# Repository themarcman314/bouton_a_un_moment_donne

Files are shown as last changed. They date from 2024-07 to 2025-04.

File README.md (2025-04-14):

## HW prototype
kicad schematic and board files as well as BOM and step files are available here.
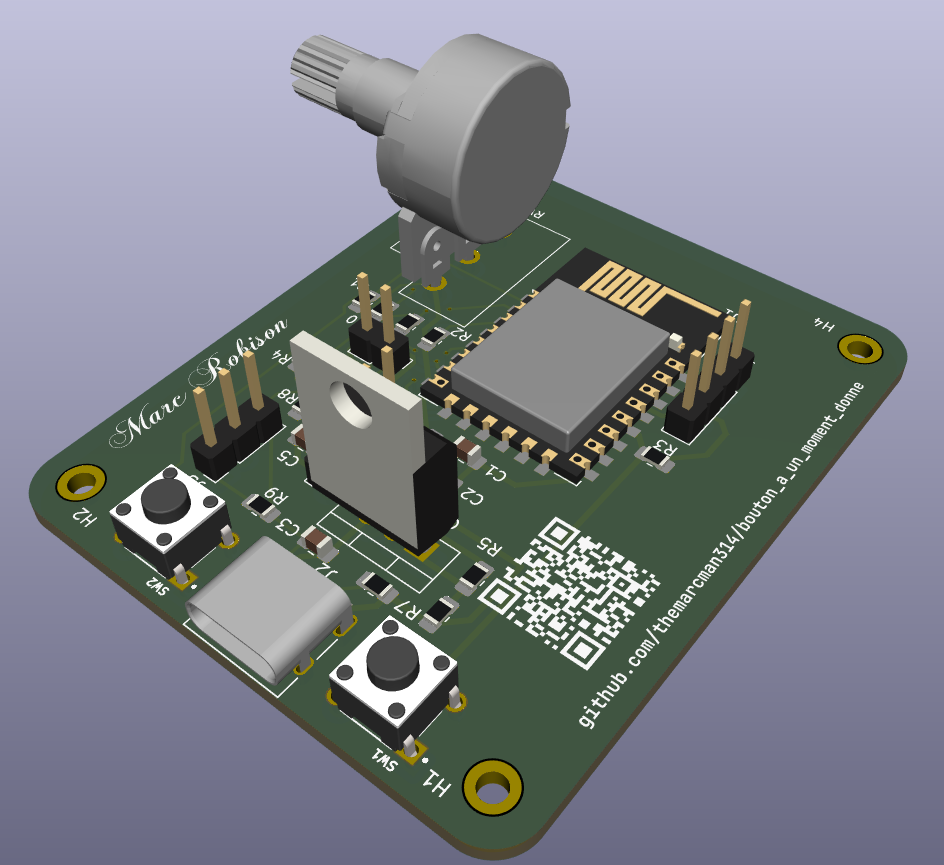
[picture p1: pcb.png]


This code is not even in alpha.

Was trying to figure out a version name so I asked chatgpt :

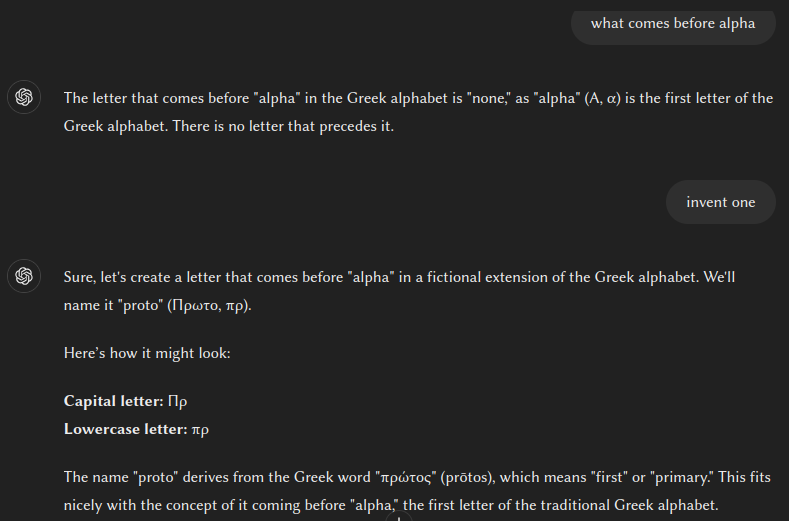
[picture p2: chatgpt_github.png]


This code is in "proto".

I know it might sound similar to some but dont confuse this with "production".

## Usage

### Clone the repo
HTTPS
```bash
$ git clone "https://github.com/themarcman314/bouton_a_un_moment_donne.git"
```
SSH
```bash
$ git clone git@github.com:themarcman314/bouton_a_un_moment_donne.git
```

### Wire I2S pins from ESP8266NodeMCU to MAX98357A DAC & class D amp
Kindly RTFM and follow wiring from here :
https://github.com/earlephilhower/ESP8266Audio?tab=readme-ov-file#i2s-dacs

### Flash firmware
Open `.ino` file with the arduino ide and click the arrow pointing right to flash.

### Configure audio files
1. Connect to the WAP with Wi-Fi enabled device.
SSID name is `fbi_van`

2. Portal with the configuration page should open automatically.
If not just go to `192.168.1.1` or any ip at all really.

3. Upload small mp3 files (2 MByte or smaller works well). My esp8266 module is limited to 4MB, I am allocating 3MB to the filesystem. Even when doing so, the amount of files that can be uploaded is limited depending on the bit rate, duration of audio, etc...
Remaining space is displayed on the main page.

Be patient when uploading a file.
Uploading a 1.1 MByte file took me 15 seconds which gives a transfering speed of about 1.1 * 8 / 15 = 0.58 MBit/s

Below is the configuration I set in arduino-ide to increase the upload speed

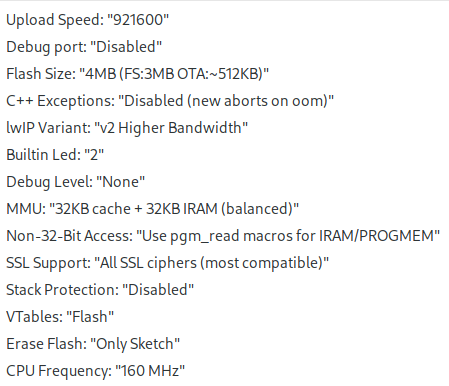
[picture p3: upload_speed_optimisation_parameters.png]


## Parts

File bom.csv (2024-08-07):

Id | Référence | Empreinte | Quantité | Désignation | Fournisseur et réf
1 | J3 | PinHeader_1x03_P2.54mm_Vertical | 1 | Conn_01x03_Pin
2 | J2 | PinHeader_1x04_P2.54mm_Vertical | 1 | Conn_01x04_Pin
3 | R1 | R_0805_2012Metric_Pad1.20x1.40mm_HandSolder | 1 | 1M
4 | C4 | C_0805_2012Metric_Pad1.18x1.45mm_HandSolder | 1 | 10uF
5 | RV1 | Potentiometer_Piher_T-16H_Single_Horizontal | 1 | R_Potentiometer
6 | A1 | SEEED_113990105 | 1 | 113990105
7 | R3 | R_0805_2012Metric_Pad1.20x1.40mm_HandSolder | 1 | 10K
8 | J1 | JST_SUR_SM02B-SURS-TF_1x02-1MP_P0.80mm_Horizontal | 1 | Conn_01x02
9 | U1 | TQFN-16-1EP_3x3mm_P0.5mm_EP1.23x1.23mm | 1 | MAX98357A
10 | R2 | R_0805_2012Metric_Pad1.20x1.40mm_HandSolder | 1 | R
11 | C3 | C_0805_2012Metric_Pad1.18x1.45mm_HandSolder | 1 | 0.1uF

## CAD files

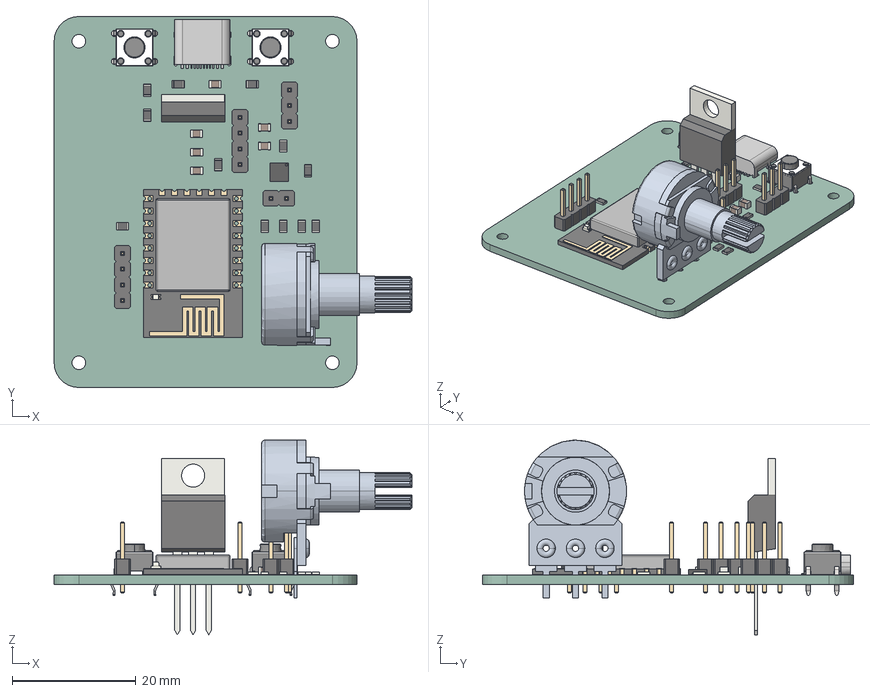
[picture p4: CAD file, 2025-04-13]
sound_box.step
57.9 x 60.0 x 31.5 mm
PinHeader_1x04_P2.54mm_Vertical x 2
QFN-16 (3x3) Part1
QFN-16 (3x3) Part2 x 16
tactileswitch-short x 2
R_0805_2012Metric x 12
TO-220-3_Vertical
ESP-12E
C_0805_2012Metric x 6
HRO TYPE-C-31-M-12
Potentiometer
PinHeader_1x02_P2.54mm_Vertical
PinHeader_1x03_P2.54mm_Vertical
sound_box_PCB

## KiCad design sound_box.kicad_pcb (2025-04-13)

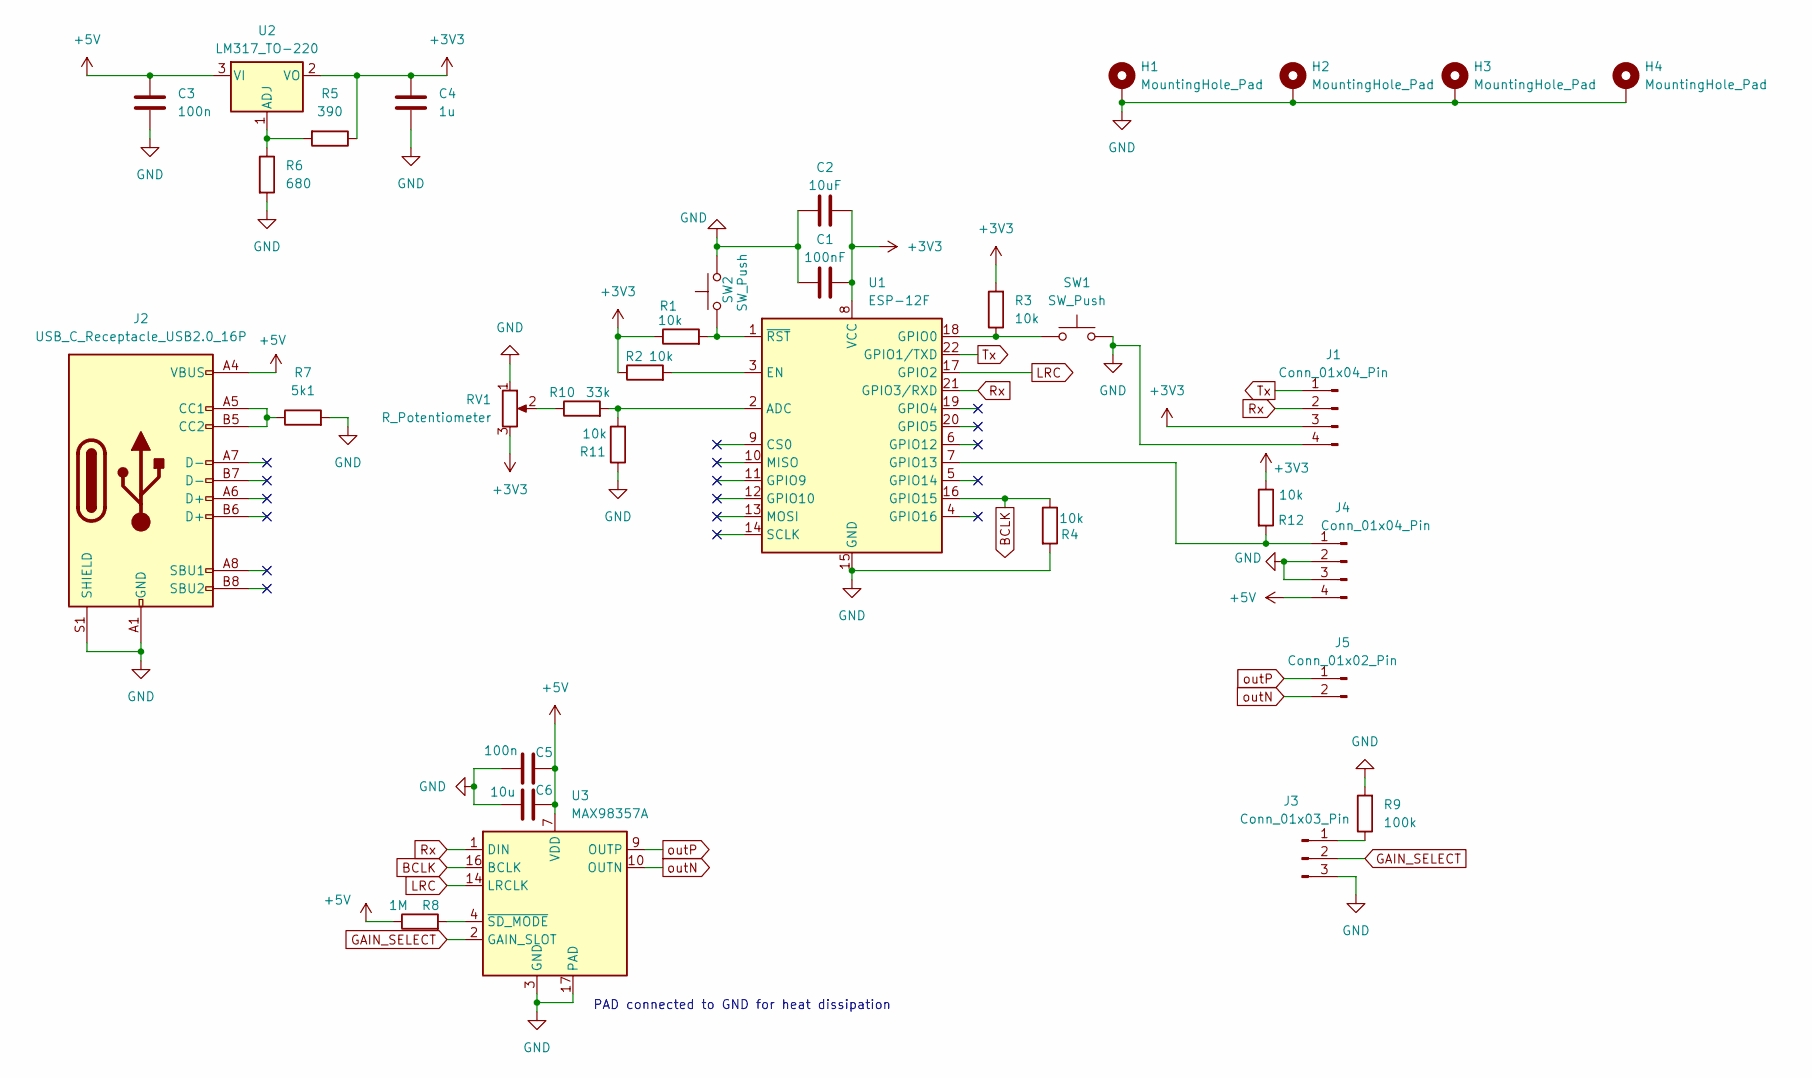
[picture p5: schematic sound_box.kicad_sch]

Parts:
C1: 100nF; C_0805_2012Metric_Pad1.18x1.45mm_HandSolder
C2: 10uF; C_0805_2012Metric_Pad1.18x1.45mm_HandSolder
C3, C5: 100n; C_0805_2012Metric_Pad1.18x1.45mm_HandSolder
C4: 1u; C_0805_2012Metric_Pad1.18x1.45mm_HandSolder
C6: 10u; C_0805_2012Metric_Pad1.18x1.45mm_HandSolder
H1, H2, H3, H4: MountingHole_Pad; MountingHole_2.2mm_M2_DIN965_Pad
J1, J4: Conn_01x04_Pin; PinHeader_1x04_P2.54mm_Vertical
J2: USB_C_Receptacle_USB2.0_16P; USB_C_Receptacle_HRO_TYPE-C-31-M-12
J3: Conn_01x03_Pin; PinHeader_1x03_P2.54mm_Vertical
J5: Conn_01x02_Pin; PinHeader_1x02_P2.54mm_Vertical
R1, R2, R3, R4, R11, R12: 10k; R_0805_2012Metric_Pad1.20x1.40mm_HandSolder
R5: 390; R_0805_2012Metric_Pad1.20x1.40mm_HandSolder
R6: 680; R_0805_2012Metric_Pad1.20x1.40mm_HandSolder
R7: 5k1; R_0805_2012Metric_Pad1.20x1.40mm_HandSolder
R8: 1M; R_0805_2012Metric_Pad1.20x1.40mm_HandSolder
R9: 100k; R_0805_2012Metric_Pad1.20x1.40mm_HandSolder
R10: 33k; R_0805_2012Metric_Pad1.20x1.40mm_HandSolder
RV1: R_Potentiometer; Potentiometer_Piher_T-16H_Single_Horizontal
SW1, SW2: SW_Push; SW_1825910-6-4
U1: ESP-12F; ESP-12E
U2: LM317_TO-220; TO-220-3_Vertical
U3: MAX98357A; TQFN-16-1EP_3x3mm_P0.5mm_EP1.23x1.23mm

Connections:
+3V3: C1.2, C2.2, C4.1, J1.3, R1.1, R2.1, R3.2, R5.1, R12.1, RV1.3, U1.8 (VCC), U2.2 (VO)
+5V: C3.1, C5.2, C6.2, J2.A4 (VBUS), J2.A9 (VBUS), J2.B4 (VBUS), J2.B9 (VBUS), J4.4, R8.1, U2.3 (VI), U3.7 (VDD), U3.8 (VDD)
BCLK: R4.1, U1.16 (GPIO15), U3.16 (BCLK)
GAIN_SELECT: J3.2, U3.2 (GAIN_SLOT)
GND: C1.1, C2.1, C3.2, C4.2, C5.1, C6.1, H1.1, H2.1, H3.1, H4.1, J1.4, J2.A1 (GND), J2.A12 (GND), J2.B1 (GND), J2.B12 (GND), J2.S1 (SHIELD), J3.3, J4.2, J4.3, R4.2, R6.2, R7.2, R9.2, R11.1, RV1.1, SW1.2, SW2.2, U1.15 (GND), U3.3 (GND), U3.11 (GND), U3.15 (GND), U3.17 (PAD)
LRC: U1.17 (GPIO2), U3.14 (LRCLK)
unnamed: J2.A5 (CC1), J2.B5 (CC2), R7.1
unnamed: J3.1, R9.1
unnamed: J4.1, R12.2, U1.7 (GPIO13)
unnamed: R10.1, RV1.2
unnamed: R10.2, R11.2, U1.2 (ADC)
unnamed: R2.2, U1.3 (EN)
unnamed: R3.1, SW1.1, U1.18 (GPIO0)
unnamed: R1.2, SW2.1, U1.1 (~RST)
unnamed: R5.2, R6.1, U2.1 (ADJ)
unnamed: R8.2, U3.4 (~SD_MODE)
Rx: J1.2, U1.21 (GPIO3/RXD), U3.1 (DIN)
Tx: J1.1, U1.22 (GPIO1/TXD)
outN: J5.2, U3.10 (OUTN)
outP: J5.1, U3.9 (OUTP)

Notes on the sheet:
PAD connected to GND for heat dissipation

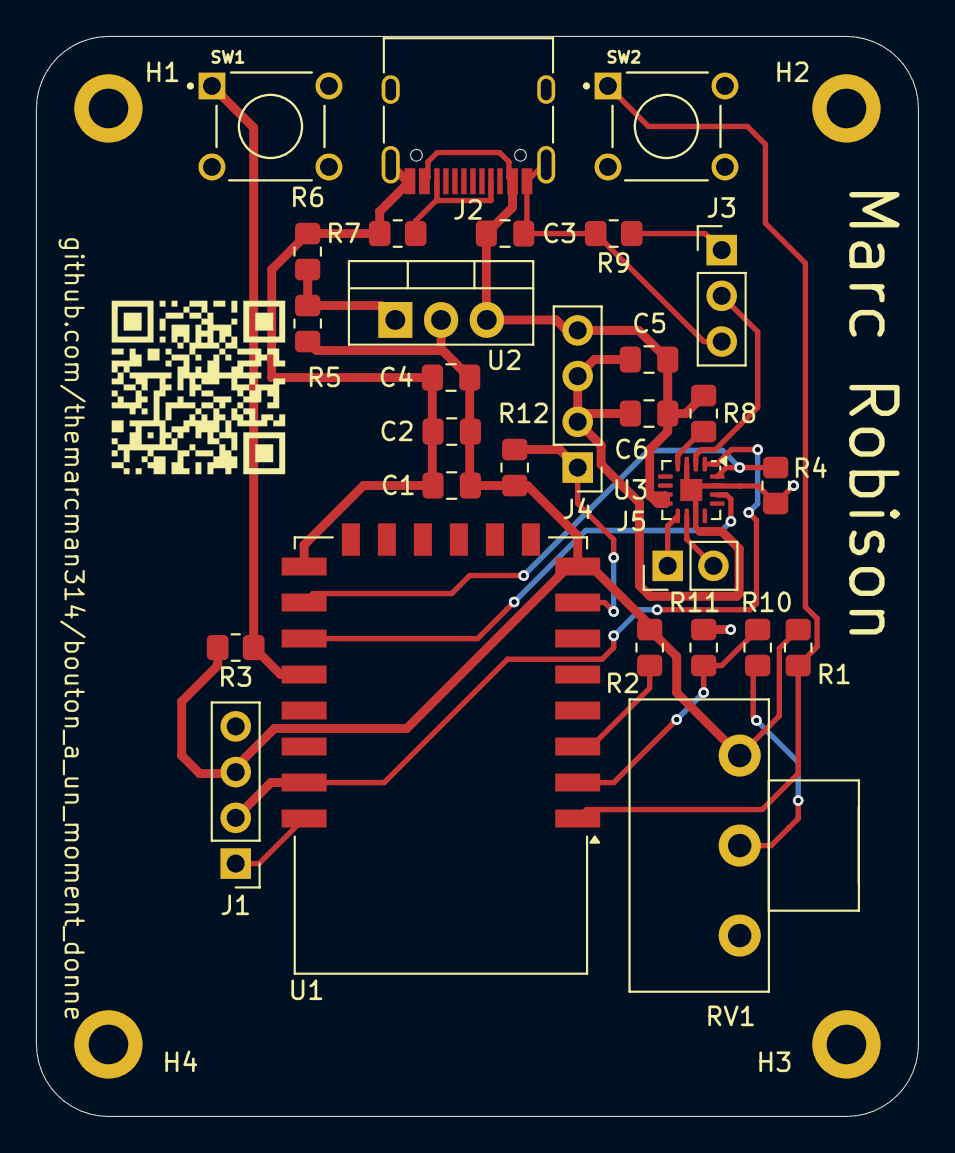
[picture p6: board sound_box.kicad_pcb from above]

Board: 2 copper layers, 49.0 x 60.0 mm, 33 parts (0 on the bottom side), 20 nets.

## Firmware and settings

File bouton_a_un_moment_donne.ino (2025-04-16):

// #include "LittleFS.h"
// #define HTTP_UPLOAD_BUFLEN 4096


#include <Arduino.h>
#include "AudioFileSourceSPIFFS.h"
#include "AudioGeneratorMP3.h"
#include "AudioOutputI2SNoDAC.h"


#include <ESP8266WiFi.h>
#include <WiFiClient.h>
#include <ESP8266WebServer.h>
#include <DNSServer.h>
#include "pages.h"
#include "style.h"

#include "ESP8266TimerInterrupt.h"

// set max space for flash
// FLASH_MAP_SETUP_CONFIG(FLASH_MAP_MAX_FS)
#ifndef APSSID
#define APSSID "fbi_van"
#define APPSK "password"
#endif

#define TIMER_INTERVAL_MS        1000

void Playsong(void);


static const char TEXT_PLAIN[] PROGMEM = "text/plain";
File uploadFile;

AudioGeneratorMP3 *mp3;
AudioFileSourceSPIFFS *file;
AudioOutputI2S *out;


String selected_file;

const byte DNS_PORT = 53;
DNSServer dnsServer;

/* Set these to your desired credentials. */
const char *ssid = APSSID;
const char *password = APPSK;

ESP8266WebServer server(80);

ESP8266Timer ITimer;

volatile bool updateVolume = false;
volatile bool stop = false;


void IRAM_ATTR TimerHandler()
{
  updateVolume = true;
}

void handleRoot() {

  FSInfo fs_info;
  SPIFFS.info(fs_info);

  // Calculate available space
  size_t totalBytes = fs_info.totalBytes;
  size_t usedBytes = fs_info.usedBytes;
  size_t freeKBytes = (totalBytes - usedBytes)*0.001;

  String main_page = index_html;

  // find available mp3 files
  Dir dir = SPIFFS.openDir("/");
  while (dir.next()) {
    String file_name = dir.fileName();
    if(file_name.endsWith(".mp3"))
      main_page += "<option value=\"" + file_name + "\">" + file_name + "</option>";
  }
  main_page += "</select><input type=\"submit\" value=\"Submit\" class=\"buttons\"></form>";
  main_page += "<p>Available space : ";
  main_page += String(freeKBytes);
  main_page += " KBytes</p>";

  main_page += R"=====(
  <h1>Delete</h1>
  <form id="del" action="/delete" method="post">
      <label for="fileDelete">Choose a file to delete :</label>
          <select name="file" id="fileDelete">
  )=====";

  // find available files
  dir = SPIFFS.openDir("/");
  while (dir.next()) {
    String file_name = dir.fileName();
    main_page += "<option value=\"" + file_name + "\">" + file_name + "</option>";
  }
  main_page += "</select><input type=\"submit\" value=\"Submit\" class=\"buttons\"></form>";
  main_page += scripts;
  main_page += "</body></html>";


  server.send(200, "text/html", main_page);
}

void handleLed() {
  digitalWrite(LED_BUILTIN, !digitalRead(LED_BUILTIN));
  handleRoot();
}

void handleCaptivePortal() {
  String header = "HTTP/1.1 302 Found\r\nLocation: http://";
  header += WiFi.softAPIP().toString();
  header += "/\r\n\r\n";
  server.sendContent(header);
  server.client().stop(); // End the current connection

  digitalWrite(LED_BUILTIN, !digitalRead(LED_BUILTIN)); // Toggle LED state
}

void replyOK() {
  server.send(200, FPSTR(TEXT_PLAIN), "");
}
void replyServerError(String msg) {
  Serial.println(msg);
  server.send(500, FPSTR(TEXT_PLAIN), msg + "\r\n");
}

void replyBadRequest(String msg) {
  Serial.println(msg);
  server.send(400, FPSTR(TEXT_PLAIN), msg + "\r\n");
}

void handleFileUpload() {
  HTTPUpload& upload = server.upload();

  // Serial.println("Upload status :" + String(upload.status));
  if (upload.status == UPLOAD_FILE_START) {
    String filename = upload.filename;
    if (!filename.startsWith("/")) { filename = "/" + filename; }
    Serial.println("Preparing to upload : " + filename);
    uploadFile = SPIFFS.open(filename, "w+");
    if (!uploadFile) {Serial.println("Create failed");}
    else{
      Serial.println("File opened");
      Serial.println("Upload starting, filename : " + String(filename));
    }
  }
  else if (upload.status == UPLOAD_FILE_WRITE) {
    // Serial.println("Writing");
    size_t bytesWritten = uploadFile.write(upload.buf, upload.currentSize);
    // Serial.println("Bytes written :" + String(bytesWritten));
    if (bytesWritten != upload.currentSize) { 
      Serial.println("Something went wrong");
      return replyServerError(F("WRITE FAILED")); }
  }
  else if (upload.status == UPLOAD_FILE_END) {
    // Serial.println("File Content:");
    // uploadFile.seek(0,SeekSet);
    // while(uploadFile.available()){
    //   Serial.write(uploadFile.read());
    // }
    uploadFile.close();
    Serial.println(String("Upload: END, Size: ") + upload.totalSize);
    handleRoot();
  }
}

void handleFileList() {
  Dir dir = SPIFFS.openDir("/");

  String file_info = "<html><body>";
  file_info += "<h1>Files</h1>";
  file_info += "<table border='1'>";
  file_info += "<tr><th>File Name</th><th>Size (bytes)</th></tr>";

  while (dir.next()) {
    String file_name = dir.fileName();
    size_t file_size = dir.fileSize();
    file_info += "<tr><td>" + file_name + "</td><td>" + String(file_size) + "</td></tr>";
  }
  file_info += "</table>";
  file_info += "</body></html>";

  server.send(200, "text/html", file_info);
}

void handleImageRequest() {
  if (SPIFFS.exists("/foyer.jpg")) {
    File file = SPIFFS.open("/foyer.jpg", "r");
    server.streamFile(file, "foyer.jpg");
    file.close();
  } 
  else {server.send(404, "text/plain", "File not found");}
}

void handleMusicSelection() {  
  selected_file = server.arg("file");
  Serial.println("Selected file : " + selected_file);
  
  File config_file;

  config_file = SPIFFS.open("/config.txt", "w+");
  if (!config_file) {Serial.println("Create failed");}
    else{
      Serial.println("File opened");
    }
  size_t bytesWritten = config_file.write(selected_file.c_str(), selected_file.length());
  Serial.println(bytesWritten);

  config_file.close();

  //Playsong();

  handleRoot();
}

void handleMusicDeletion() {
  String selected_file = server.arg("file");
  Serial.println("Selected file : " + selected_file);

  const char *file_name = selected_file.c_str();

  if(SPIFFS.exists(file_name)) {
    Serial.println(selected_file + "File exists");
    SPIFFS.remove(file_name);
  }
  else Serial.println("File does not exist");
  handleRoot();
}

void setup() {
  pinMode(LED_BUILTIN, OUTPUT);
  pinMode(D7, INPUT);

  digitalWrite(LED_BUILTIN, HIGH);
  Serial.begin(115200);

  SPIFFSConfig cfg;
  cfg.setAutoFormat(false);
  SPIFFS.setConfig(cfg);
  if(SPIFFS.begin() == true)
      Serial.print("\r\n\nFS mounted\r\n");
  else Serial.print("\r\n\nProblem mounting FS!\r\n");

  if(SPIFFS.exists("/foyer.jpg") == true)
    Serial.println("File exists");
  else Serial.println("File does not exist");

  SPIFFS.gc();

  File f = SPIFFS.open("/foyer.jpg", "r");
  if (!f) {
    Serial.println("file open failed");
  }
  else Serial.println("File opened");

  IPAddress local_IP(192,168,1,1);
  IPAddress gateway(192,168,1,1);
  IPAddress subnet(255,255,255,0);
  WiFi.softAPConfig(local_IP, gateway, subnet);
   
  WiFi.softAP(ssid/*, password*/);
  Serial.print("\r\nConfiguring access point...\r\n");

  IPAddress myIP = WiFi.softAPIP();
  Serial.print("AP IP address: ");
  Serial.println(myIP);

  server.on("/", handleRoot);
  server.on("/toggle", handleLed);
 
  server.on("/style.css", [] {
    server.send(200, "text/css", css_file);
  });
  server.on("/foyer.jpg", HTTP_GET, handleImageRequest);

  server.onNotFound(handleRedirect);  // Redirect all other URLs to the root handler
  
  server.on("/edit", HTTP_POST, replyOK, handleFileUpload);
  server.on("/select", handleMusicSelection);
  server.on("/redirect", handleRedirect);
  server.on("/delete", handleMusicDeletion);


  server.on("/list", HTTP_GET, handleFileList);

  dnsServer.start(DNS_PORT, "*", local_IP);

  server.begin();
  Serial.println("HTTP server started");

  out = new AudioOutputI2S();
  mp3 = new AudioGeneratorMP3();
  if (ITimer.attachInterruptInterval(TIMER_INTERVAL_MS * 100, TimerHandler))
  {
    Serial.print("Starting  ITimer OK");
  }
  else
    Serial.println(F("Can't set ITimer correctly. Select another freq. or interval"));
}

void loop() {
  dnsServer.processNextRequest();
  server.handleClient();
  if(digitalRead(D7) == 0)
  {
    Playsong();
  }
}


void handleRedirect() {
  server.send(200, "text/html", redirect_page);
}

void Playsong(void)
{
  delay(20);
  Serial.println("Opening file...");
  File conf_file = SPIFFS.open("/config.txt", "r");
  String file_to_play = conf_file.readString();
  Serial.print(file_to_play);

  const char *file_name = file_to_play.c_str();
  Serial.print(file_name);
  Serial.println();

  if(SPIFFS.exists(file_name)) {
    Serial.println(selected_file + "File exists");
  }
  else {Serial.println(selected_file + "File does not exist :(");}

  file = new AudioFileSourceSPIFFS(file_name);
  // out = new AudioOutputI2S();
  //out->SetGain(1);
  // out->SetGain(analogRead(A0)/1023);
  mp3->begin(file, out);
  
  while(1) {
    if (mp3->isRunning()) {

      if (updateVolume) {
      updateVolume = false;

      float volume = analogRead(A0) / 1023.0;
      out->SetGain(volume);
      }

    if (!mp3->loop() || !digitalRead(D7)) mp3->stop(); 
    }
    else {
      break;
    }
  }
}

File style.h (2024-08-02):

const char css_file[] PROGMEM = R"=====(
label {
        font-weight: bold;
        font-size:2vw;
        color:green;
}
select {
        font-size:2vw;
        padding: 1em;
        color: white; /* Text color */
        background-color: green; /* Background color */
        border-radius: .5em; /* Rounded corners */
}
.buttons {
        font-size:3vw;
        background:teal;
        border-radius:.3em;
        color:white
}
::-webkit-file-upload-button {
        color:white;
        background:green;
}
img {
        display: block;
        max-width: 100%;
}
body
{
        color: white;
        background-color: black;
        margin-left: 0;
        margin-top: 0;
        margin-right: 0;
        text-align: center;
}
main
{
        max-width: 800px ;
        margin: auto ;
        display: block;
}
h1
{
        color: orange;
        text-align: center;
}
h2
{
        text-align: center;
        color: teal;
        margin: 5%;
}
.loader
{
  position: fixed;
  top: 0;
  left: 0;
  width: 100vw;
  height: 100vh;
  display: flex;
  align-items: center;
  justify-content: center;
  background: #333333;
  transition: opacity 0.75, visibility 0.75;
}
.loader--hidden
{
  opacity: 0;
  visibility: hidden;
}
.loader::after
{
  content: "";
  width: 75px;
  height: 75px;
  border: 15px solid #dddddd;
  border-top-color: #009578;
  border-radius: 50%;
  animation: loading 0.75s ease infinite;
}
@keyframes loading
{
  from { transform: rotate(0turn)}
  to { transform: rotate(1turn)}
}
)=====";

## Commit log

2024-07-06 max fs size but still error when sending file
    [bouton_a_un_moment_donne.ino]
2024-07-06 read file ok upload file fails
    [bouton_a_un_moment_donne.ino]
2024-07-07 switched to SPIFFS FS from LittleFS
2024-07-08 playing audio from web button
2024-07-08 buttons bring back home page
2024-07-09 fixed image from overflowing
    [style.h]
2024-07-11 pretty buttons
2024-07-12 new browser redirect solution for android devices
2024-07-14 added delete section, centered buttons
2024-07-22 fixed image not loading
    [bouton_a_un_moment_donne.ino]
2024-08-02 fixed file upload not completing
    [bouton_a_un_moment_donne.ino, style.h]
2024-08-04 loading animation for delete and play buttons
2024-08-07 hw prototype
    [bom.csv, new_speaker.kicad_pcb, new_speaker.kicad_sch]
2024-08-08 fixed nodemcu footprint
    [new_speaker.kicad_pcb, new_speaker.kicad_sch]
2024-08-08 updated 3d render for new footprint
2024-08-09 added mounting pads and rounded corners
    [new_speaker.kicad_pcb, new_speaker.kicad_sch]
2024-08-09 fixed button input and added gain silkscreen
    [new_speaker.kicad_pcb, new_speaker.kicad_sch]
2024-08-09 use actual button to play audio
2024-08-26 updated resistor value in sch
    [new_speaker.kicad_sch]
2025-04-13 updated pcb
    [new_speaker.kicad_pcb, new_speaker.kicad_sch, sound_box.kicad_pcb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]
2025-04-16 stop and replay audio when pressing button again
